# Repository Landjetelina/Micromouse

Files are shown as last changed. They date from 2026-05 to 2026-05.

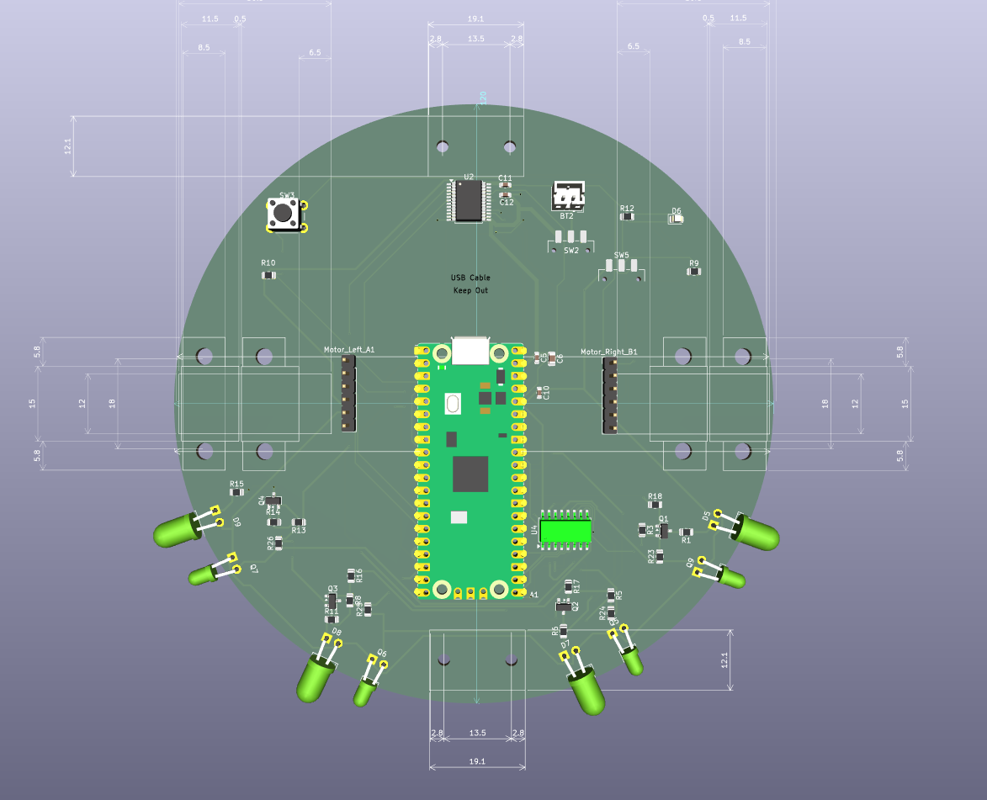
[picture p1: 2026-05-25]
hardware/pcb_3d.png

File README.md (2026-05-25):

# Šnajderovi šamani
- Magdalena Grbavac
- Patrik Landeka
- Antea Parat

## Natjecanje: 
31.5. u Algebri -> [Lokacija na karti](https://maps.app.goo.gl/GhEoACbUTYHz3x7r8)

## Requirements:
- Kicad = hardware dizajn
- VScode -> eksetenzija MicroPico
- micro USB podatkovni kabel (stari punjač od mobitela koji podržava prenošenje podataka, a ne samo punjenje)

### Tips:
- klonirajte ovaj repo u VScode pa odmah imate pristup kodovima
- za updejt datoteke:

  ```
  1. git add .
  2. git commit -m "poruka koja ide s promjenom"
  3. git push origin main *ako javlja grešku prvo napraviti pull
  4. git pull origin main * po potrebi, preporučam da to bude prvi korak ako niste zadnji radili na projektu
  ```

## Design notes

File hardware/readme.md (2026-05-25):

# Micromouse Hardware

Autonomous maze-solving robot based on Raspberry Pi Pico.

## Components

| Component | Description |
|---|---|
| Raspberry Pi Pico | Main microcontroller (RP2040) |
| TB6612FNG | Dual motor driver |
| TSAL6102 | IR LED emitter (940nm) x4 |
| TEFT4300 | IR phototransistor x4 |
| CD74HC4053 | Analog multiplexer (4:1) |
| N20 motors | DC motors with encoders x2

## Pin Assignment

| GPIO | Signal | Description 
|--- |---|---
| GPIO0 | IR_left | IR LED emitter - left 
| GPIO1 | IR_left-right | IR LED emitter - left-center 
| GPIO2 | IR_right-left | IR LED emitter - right-center 
| GPIO3 | IR_right | IR LED emitter - right 
| GPIO4 | Left_motor_1 | Motor driver AIN1 
| GPIO5 | Left_motor_2 | Motor driver AIN2
| GPIO6 | Right_motor_1 | Motor driver BIN1 
| GPIO7 | Right_motor_2 | Motor driver BIN2 
| GPIO8 | Speed_Left | PWM left motor 
| GPIO9 | Speed_Right | PWM right motor 
| GPIO10  | A1 | Encoder left A 
| GPIO11  | A2 | Encoder left B 
| GPIO12  | B1 | Encoder right A 
| GPIO13  | B2 | Encoder right B 
| GPIO16  | MUX_foto_0 | MUX select S0 
| GPIO17  | MUX_foto_1 | MUX select S1 
| GPIO18  | MUX_foto_2 | MUX select S2 
| GPIO26  | IRT_READ | ADC - phototransistor via MUX 

## Schematics

Designed in KiCad 10.0.0.
See `project1.kicad_sch` for full schematic.

## IR Sensor Circuit

Each IR pair consists of:
- **TSAL6102** emitter with 100Ω series resistor (3.3V)
- **TEFT4300** phototransistor with 10kΩ pull-up to 3.3V
- 4 phototransistors multiplexed through CD74HC4053 to single ADC pin

## Motor Driver

TB6612FNG driven at 3.3V logic, motor supply from LiPo battery via VSYS.
PWM frequency: 1kHz.

## Power

- LiPo single cell (3.7V) via JST PH connector
- VSYS powers motor driver
- 3.3V rail powers logic and sensors

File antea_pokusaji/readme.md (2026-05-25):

## Popravci, opažanja
- fotosenzori su bili obrnuti, Q5 je skroz zamjenjen => sad rade svi
- rad IR ledice moguć provjeriti s kamerom
- kvalitetnija brzina okretanja dobije se frekvencijomm 500 umjesto 1000 (manje modificiranja brzine)
- zamjenjeni su motor left i right na pcbu ("sjever" su ledice, znači desni je left, a lijevi je right --> napisano markerom)
- ne stisnuti kotače do kraja jer osovina izlazi kod konektora i ako ju tamo nešto češe, ide sporije
- bolje jedna umjesto 2 coaster balls (u suprotnom se jako jako jako slabo kreće), dovoljno je težak straga i ide sporo da to ne bi trebao biti problem + baterija premještena gore da ne smeta u vožnji 
- da bi se program pokrenuo treba biti nazvan "main.py"
- reset tipka ne radi ništa kada je uploadan program na robota, samo na sekundu ga zaustavi i normalno nastavlja dalje
- pri uključenju na laptop, pokreće se uploadani program jer pico vidi dovod napona s laptopa no onda ne rade baš fototranz (nez zaš, to je neki bug, jer "run this file on pico" i "upload this file" rade normalno i bez problemma)

### prebacivanje programa
1. desni klik na program i "upload file"
2. provjera pohrane se može preko ispod navedenih komandi
3. isključiti pico od laptopa, OFF pa ON i onda će sam krenuti

### terminal i provjera pohrane
``` 
import os
os.listdir()
os.remove()
```

### ideje za daljnju implementaciju 
- mapiranje "desnom rukom" bi moglo trajati iznimno dugo s obzirom da je brzina motora užasna
- zadržati frekveniciju motora na 500, eventualno malo sniziti da se smanji pogreška
- razmotriti potrebu PID regulatora

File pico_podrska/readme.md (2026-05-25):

RPI_PICO... = firmware za Pico 
- držati bootset (bijela tipka na Picu) dok se uštekava u komp
- kad se otvori skočni prozor file explorera za Pico, drag and drop .uf2 file na njega
- prozor će se zatvoriti i to će biti to, firmware je postavljen

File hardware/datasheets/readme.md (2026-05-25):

Datasheets komponenti koje su nam bitne
- Raspberry Pi Pico
- IR ledice
- fototranzistori
- N20 DC motori s enkoderima
- motor driver
- mux

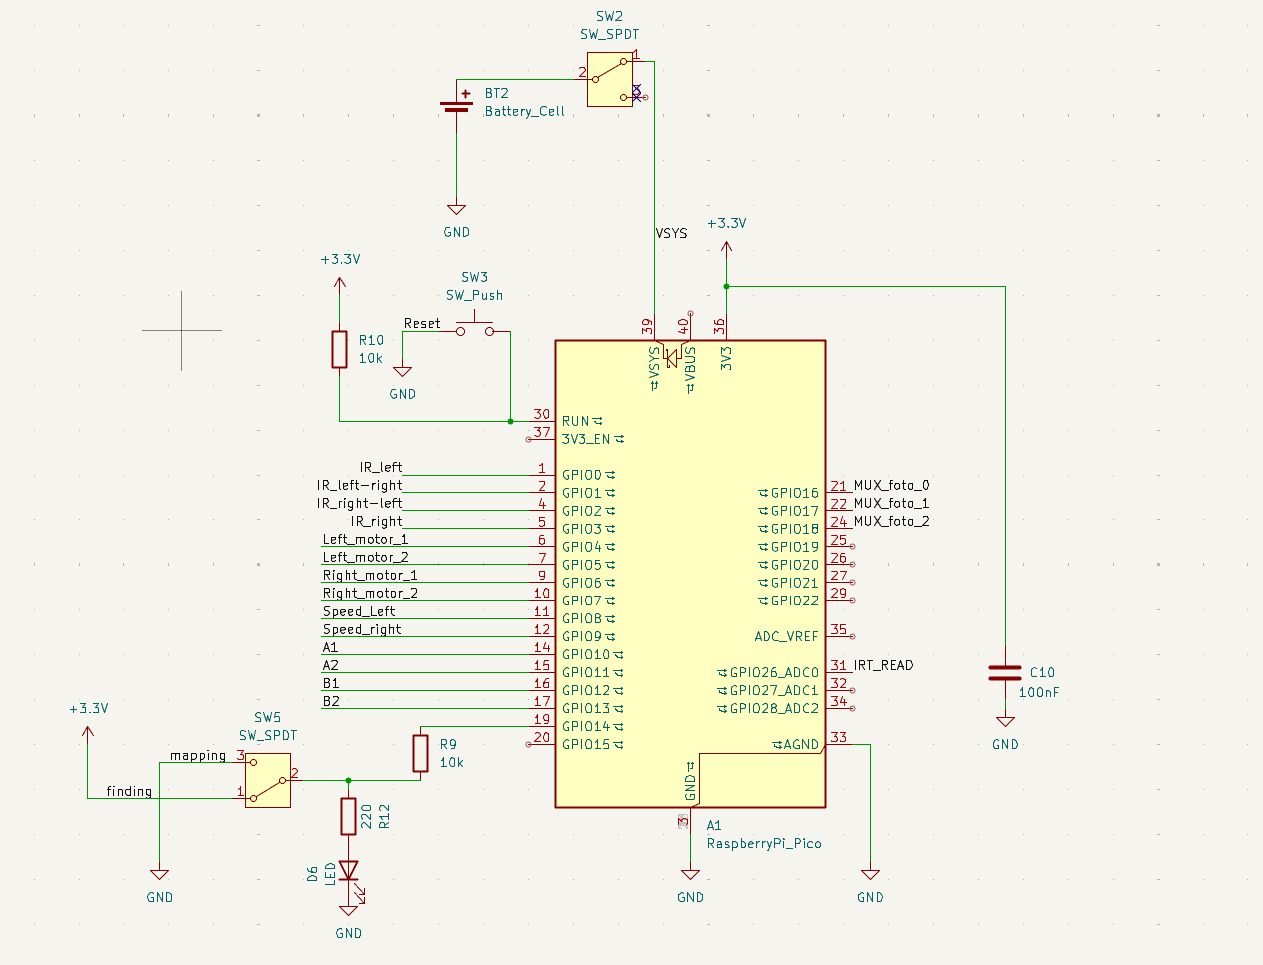
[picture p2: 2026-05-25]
hardware/pico.png

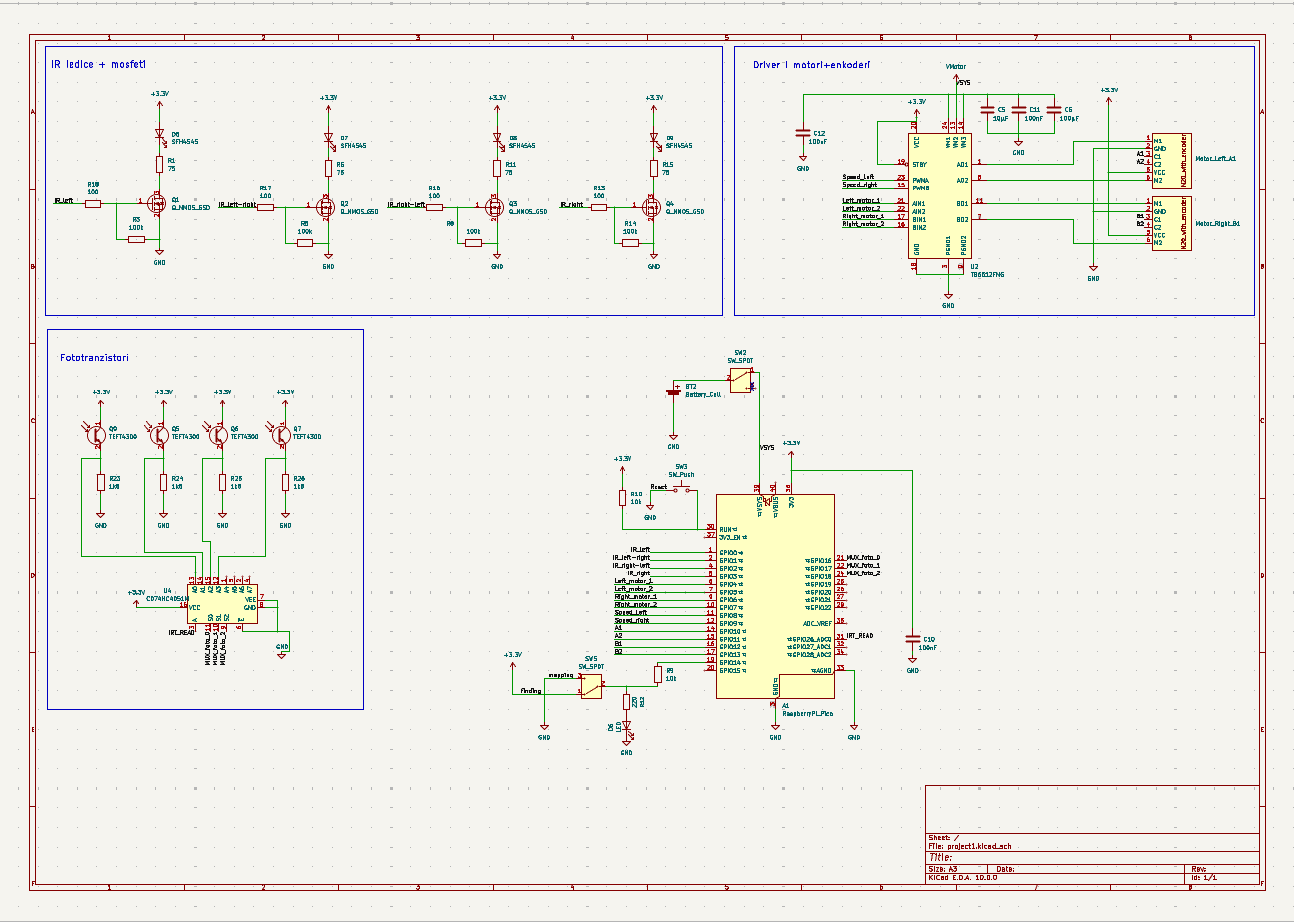
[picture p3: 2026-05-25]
hardware/shema.png

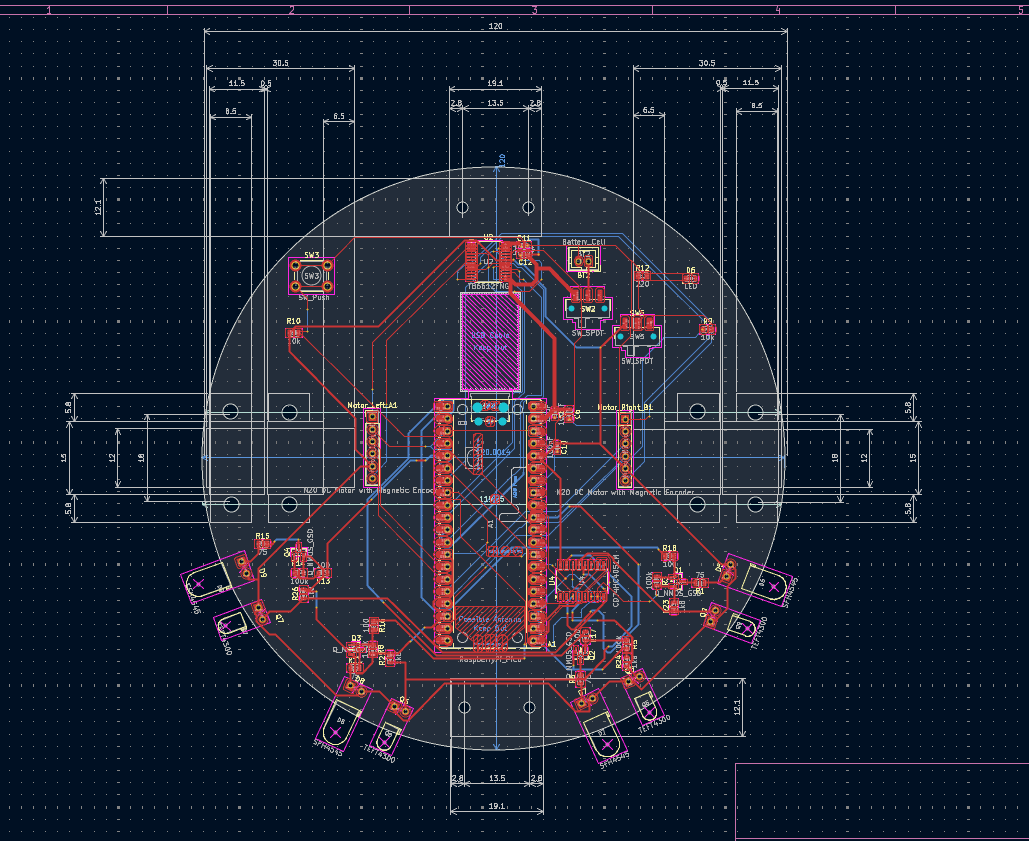
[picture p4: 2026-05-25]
hardware/pcb.png

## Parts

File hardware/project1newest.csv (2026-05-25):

Reference | Qty | Order Qty | Value | DNP | Exclude from BOM | Exclude from Board | Footprint | Datasheet | MPN | Manufacturer | Mouser | Polulu #item
A1 | 1 | 1 | RaspberryPi_Pico |  |  |  | Module:RaspberryPi_Pico_Common_Unspecified | https://datasheets.raspberrypi.com/pico/pico-datasheet.pdf | RP2040-PICO-HDR | Olimex Ltd. | 909-RP2040-PICO-HDR
BT2 | 1 | 1 | Battery_Cell |  |  |  | Connector_JST:JST_PH_B2B-PH-K_1x02_P2.00mm_Vertical |  | B2B-PH-K-S(LF)(SN) | JST Commercial | 306-B2BPHKSLFSNPP
C5 | 1 | 3 | 10ÂµF |  |  |  | Capacitor_SMD:C_0603_1608Metric |  | GRM188R60J106ME47D | Murata Electronics | 81-GRM188R60J106ME47
C6 | 1 | 3 | 100ÂµF |  |  |  | Capacitor_SMD:C_0805_2012Metric |  | GRM21BR60G107ME1L | Murata Electronics | 81-GRM21BR60G107ME1L
C10,C11,C12 | 3 | 6 | 100nF |  |  |  | Capacitor_SMD:C_0603_1608Metric |  | GRM188R72A104KA35D | Murata Electronics | 81-GRM188R72A104KA35
D1,D2,D3,D4 | 4 | 8 | TSAL6102 |  |  |  | LED_THT:LED_D5.0mm_Horizontal_O3.81mm_Z3.0mm |  | TSAL6102 | Vishay Semiconductors | 78-TSAL6102
D6 | 1 | 1 | LED |  |  |  | LED_SMD:LED_0805_2012Metric |  | 604-APT1608CGCK | Kingbright | 604-APT1608CGCK
Motor_Left_A1,Motor_Right_B1 | 2 | 2 | N20 DC Motor with Magnetic Encoder |  |  |  | Connector_PinHeader_2.54mm:PinHeader_1x06_P2.54mm_Vertical |  | 4639 | Adafruit | 485-4639
Q1,Q2,Q3,Q4 | 4 | 8 | Q_NMOS_GSD |  |  |  | Package_TO_SOT_SMD:SOT-23 |  | SI2302CDS-T1-GE3 | Vishay Semiconductors | 781-SI2302CDS-T1-GE3
Q5,Q6,Q7,Q9 | 4 | 8 | TEFT4300
R1,R6,R11,R15 | 4 | 8 | 68 |  |  |  | Resistor_SMD:R_0805_2012Metric |  | CRCW080568R0FKEA | Vishay | 71-CRCW080568R0FKEA
R3,R5,R8,R14 | 4 | 8 | 100k |  |  |  | Resistor_SMD:R_0805_2012Metric |  | CRCW0805100KFKEAC | Vishay | 71-CRCW0805100KFKEAC
R9,R10 | 2 | 6 | 10k |  |  |  | Resistor_SMD:R_0805_2012Metric |  | CRCW080510K0FKEAC | Vishay | 71-CRCW080510K0FKEAC
R12 | 1 | 3 | 220 |  |  |  | Resistor_SMD:R_0805_2012Metric |  | CRCW0805220RFKEAC | Vishay | 71-CRCW0805220RFKEAC
R13,R16,R17,R18 | 4 | 8 | 100 |  |  |  | Resistor_SMD:R_0805_2012Metric |  | CRCW0805100RFKEAC | Vishay | 71-CRCW0805100RFKEAC
R23,R24,R25,R26 | 4 | 8 | 1k8 |  |  |  | Resistor_SMD:R_0805_2012Metric |  | CRCW08051K80FKEAC | Vishay | 71-CRCW08051K80FKEAC
SW2,SW5 | 2 | 3 | SW_SPDT |  |  |  | Button_Switch_SMD:SW_SPDT_CK_JS102011SAQN |  | JS102011SAQN | C&K | 611-JS102011SAQN
SW3 | 1 | 2 | SW_Push |  |  |  | Button_Switch_THT:SW_PUSH_6mm |  | TL1105SPF160Q | E-Switch | 612-TL1105SP
U2 | 1 | 1 | TB6612FNG |  |  |  | Package_SO:SSOP-24_5.3x8.2mm_P0.65mm | https://toshiba.semicon-storage.com/us/product/linear/motordriver/detail.TB6612FNG.html | TB6612FNG,C,8,EL | Toshiba | 757-TB6612FNGC8EL
U4 | 1 | 1 | CD74HC4051M |  |  |  | Package_SO:SOIC-16_4.55x10.3mm_P1.27mm | http://www.ti.com/lit/ds/symlink/cd74hc4051.pdf | CD74HC4051M96 | Texas Instruments | 595-CD74HC4051M96
Brackets za motore par | 2 | 3 |  |  |  |  |  | https://www.pololu.com/product/989/specs#lightbox-picture0J771;main-pictures |  |  |  | 989
Kotaèi par (32x7mm) | 1 | 2 |  |  |  |  |  |  |  |  |  | 1088
kuglica (10mm = 0.375 in) | 2 | 4 |  |  |  |  |  | https://www.pololu.com/file/0J1636/pololu-ball-caster-with-0-375in-ball.pdf |  |  |  | 950

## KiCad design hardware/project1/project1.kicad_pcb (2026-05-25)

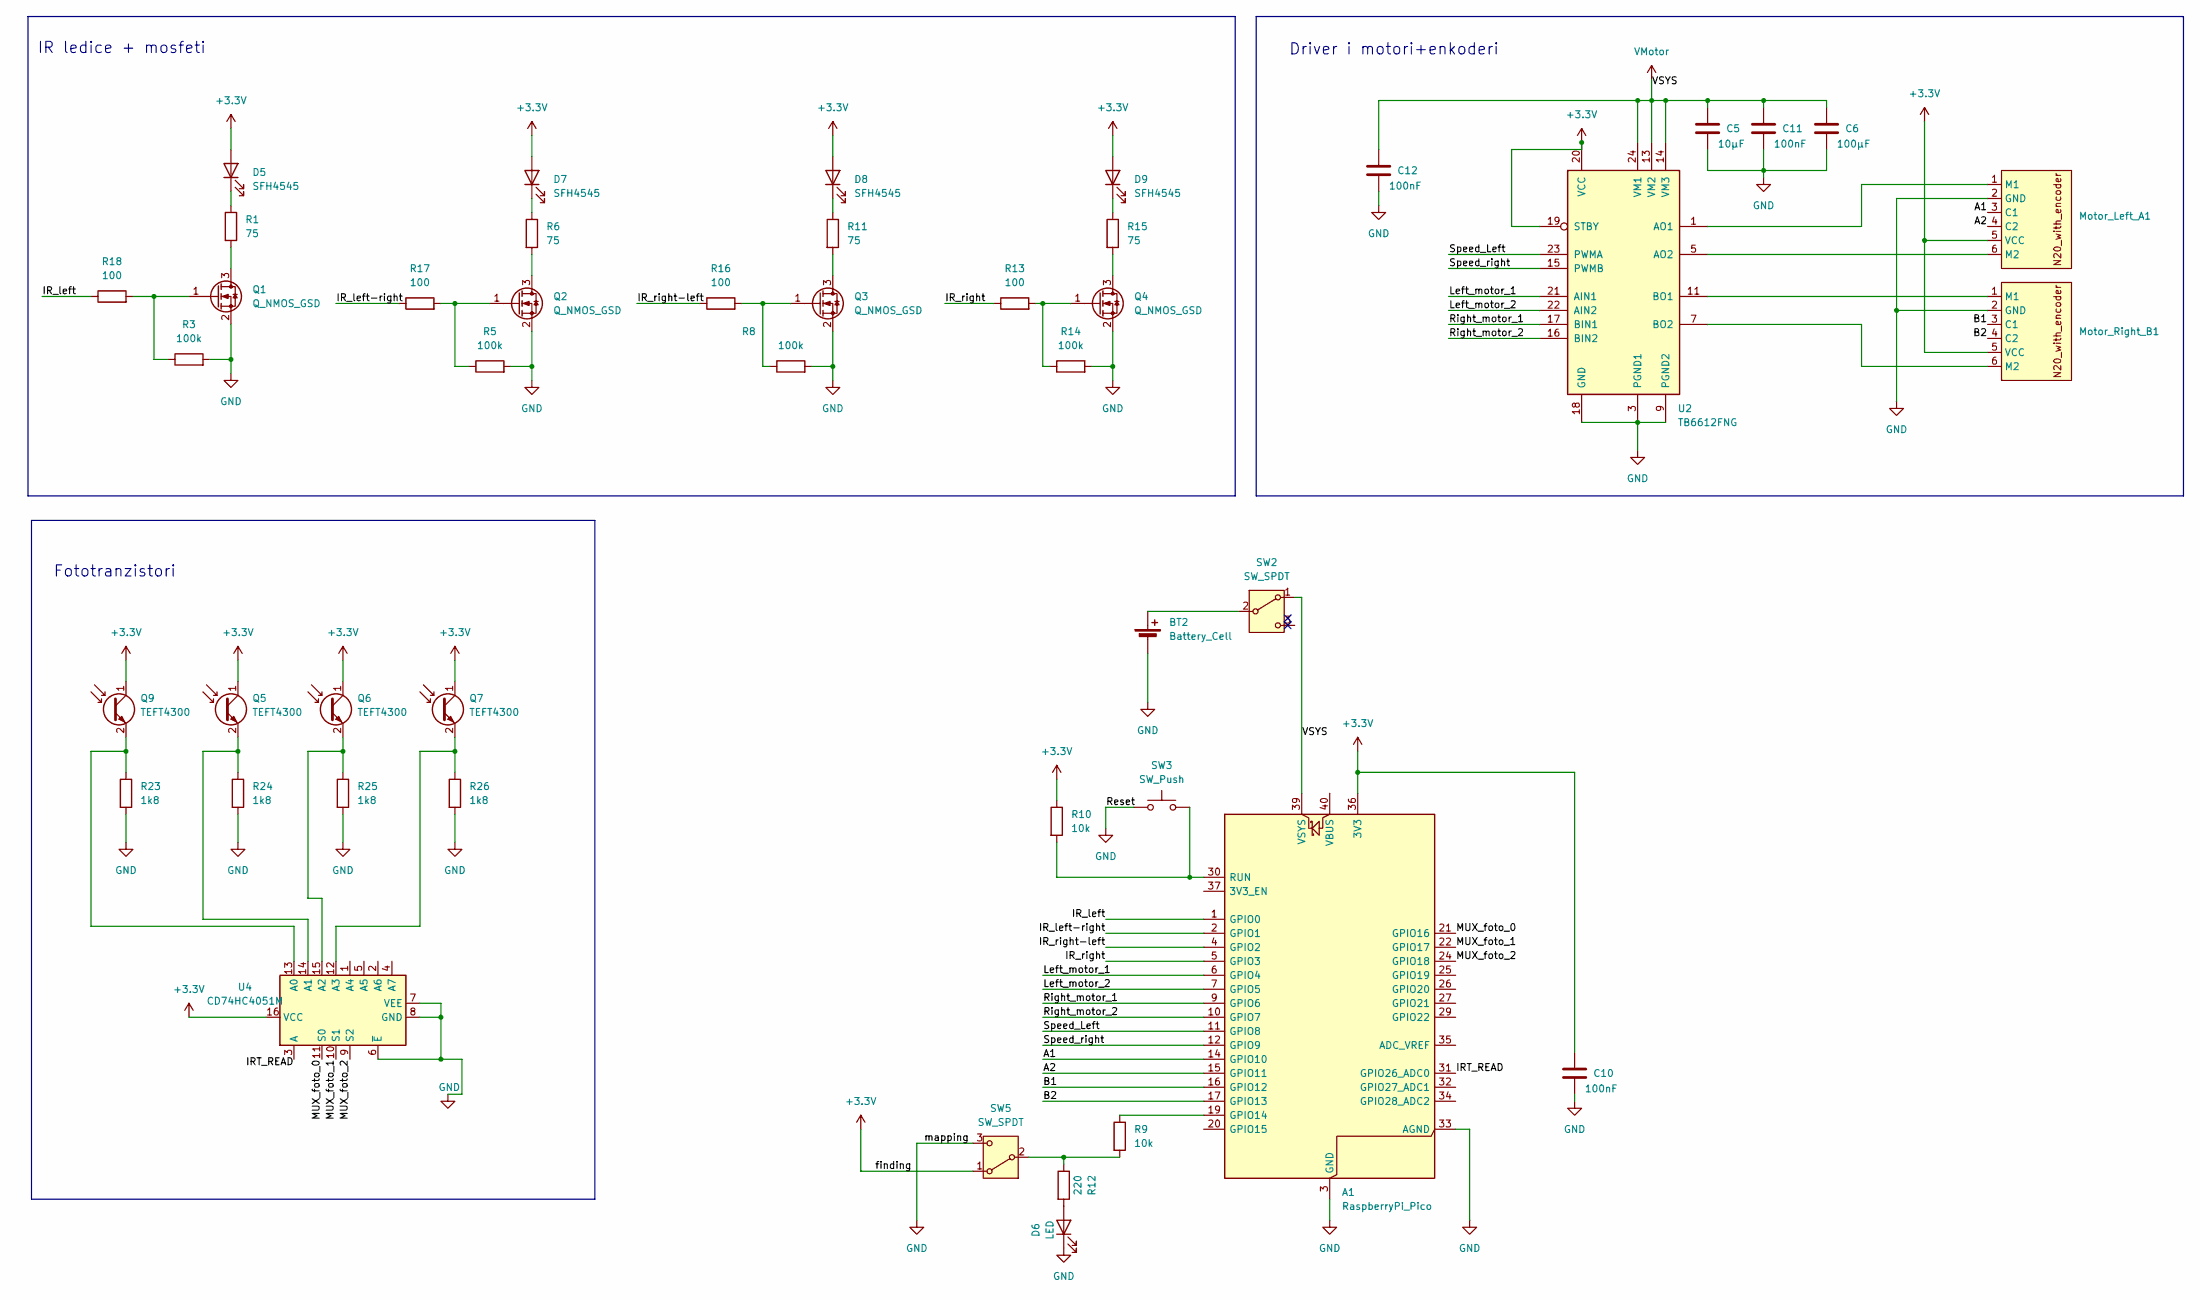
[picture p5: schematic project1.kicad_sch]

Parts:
A1: RaspberryPi_Pico; RaspberryPi_Pico_Common_Unspecified; MPN RP2040-PICO-HDR; Mouser 909-RP2040-PICO-HDR
BT2: Battery_Cell; JST_PH_B2B-PH-K_1x02_P2.00mm_Vertical; MPN B2B-PH-K-S(LF)(SN); Mouser 306-B2BPHKSLFSNPP
C5: 10µF; C_0603_1608Metric; MPN GRM188R60J106ME47D; Mouser 81-GRM188R60J106ME47
C6: 100µF; C_0805_2012Metric; MPN GRM21BR60G107ME1L; Mouser 81-GRM21BR60G107ME1L
C10, C11, C12: 100nF; C_0603_1608Metric; MPN GRM188R72A104KA35D; Mouser 81-GRM188R72A104KA35
D5, D7, D8, D9: SFH4545; LED_D5.0mm_Horizontal_O3.81mm_Z3.0mm; Manufacturer_Part_Number SFH 4545
D6: LED; LED_0805_2012Metric; MPN 604-APT1608CGCK; Mouser 604-APT1608CGCK
Motor_Left_A1: N20 DC Motor with Magnetic Encoder; PinHeader_1x06_P2.54mm_Vertical; MPN 4639; Mouser 485-4639
Motor_Right_B1: N20 DC Motor with Magnetic Encoder; PinHeader_1x06_P2.54mm_Vertical; MPN 4639; Mouser 485-4639
Q1, Q2, Q3, Q4: Q_NMOS_GSD; SOT-23; MPN SI2302CDS-T1-GE3; Mouser 781-SI2302CDS-T1-GE3
Q5, Q6, Q7, Q9: TEFT4300; LED_D3.0mm_Horizontal_O3.81mm_Z2.0mm; Manufacturer_Part_Number TEFT4300
R1, R6, R11, R15: 75; R_0805_2012Metric; MPN CRCW080568R0FKEA; Mouser 71-CRCW080568R0FKEA
R3, R5, R8, R14: 100k; R_0805_2012Metric; MPN CRCW0805100KFKEAC; Mouser 71-CRCW0805100KFKEAC
R9, R10: 10k; R_0805_2012Metric; MPN CRCW080510K0FKEAC; Mouser 71-CRCW080510K0FKEAC
R12: 220; R_0805_2012Metric; MPN CRCW0805220RFKEAC; Mouser 71-CRCW0805220RFKEAC
R13, R16, R17, R18: 100; R_0805_2012Metric; MPN CRCW0805100RFKEAC; Mouser 71-CRCW0805100RFKEAC
R23, R24, R25, R26: 1k8; R_0805_2012Metric; MPN CRCW08051K80FKEAC; Mouser 71-CRCW08051K80FKEAC
SW2, SW5: SW_SPDT; SW_SPDT_CK_JS102011SAQN; MPN JS102011SAQN; Mouser 611-JS102011SAQN
SW3: SW_Push; SW_PUSH_6mm; MPN TL1105SPF160Q; Mouser 612-TL1105SP
U2: TB6612FNG; SSOP-24_5.3x8.2mm_P0.65mm; MPN TB6612FNG,C,8,EL; Mouser 757-TB6612FNGC8EL
U4: CD74HC4051M; SOIC-16_4.55x10.3mm_P1.27mm; MPN CD74HC4051M96; Mouser 595-CD74HC4051M96

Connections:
+3.3V: A1.36 (3V3), C10.1, D5.2 (A), D7.2 (A), D8.2 (A), D9.2 (A), Motor_Left_A1.5 (VCC), Motor_Right_B1.5 (VCC), Q5.1 (C), Q6.1 (C), Q7.1 (C), Q9.1 (C), R10.1, SW5.1 (A), U2.19 (STBY), U2.20 (VCC), U4.16 (VCC)
/A1: A1.14 (GPIO10), Motor_Left_A1.3 (C1)
/A2: A1.15 (GPIO11), Motor_Left_A1.4 (C2)
/B1: A1.16 (GPIO12), Motor_Right_B1.3 (C1)
/B2: A1.17 (GPIO13), Motor_Right_B1.4 (C2)
/IRT_READ: A1.31 (GPIO26_ADC0), U4.3 (A)
/IR_left: A1.1 (GPIO0), R18.1
/IR_left-right: A1.2 (GPIO1), R17.1
/IR_right: A1.5 (GPIO3), R13.1
/IR_right-left: A1.4 (GPIO2), R16.1
/Left_motor_1: A1.6 (GPIO4), U2.21 (AIN1)
/Left_motor_2: A1.7 (GPIO5), U2.22 (AIN2)
/MUX_foto_0: A1.21 (GPIO16), U4.11 (S0)
/MUX_foto_1: A1.22 (GPIO17), U4.10 (S1)
/MUX_foto_2: A1.24 (GPIO18), U4.9 (S2)
/Right_motor_1: A1.9 (GPIO6), U2.17 (BIN1)
/Right_motor_2: A1.10 (GPIO7), U2.16 (BIN2)
/Speed_Left: A1.11 (GPIO8), U2.23 (PWMA)
/Speed_right: A1.12 (GPIO9), U2.15 (PWMB)
GND: A1.3 (GND), A1.8 (GND), A1.13 (GND), A1.18 (GND), A1.23 (GND), A1.28 (GND), A1.33 (AGND), A1.38 (GND), BT2.2 (-), C5.2, C6.2, C10.2, C11.2, C12.2, D6.1 (K), Motor_Left_A1.2 (GND), Motor_Right_B1.2 (GND), Q1.2 (S), Q2.2 (S), Q3.2 (S), Q4.2 (S), R3.2, R5.2, R8.2, R14.2, R23.2, R24.2, R25.2, R26.2, SW3.1, SW5.3 (C), U2.3 (PGND1), U2.4 (PGND1), U2.9 (PGND2), U2.10 (PGND2), U2.18 (GND), U4.6 (~E), U4.7 (VEE), U4.8 (GND)
unnamed: A1.19 (GPIO14), R9.1
unnamed: A1.30 (RUN), R10.2, SW3.2
unnamed: BT2.1 (+), SW2.2 (B)
unnamed: D5.1 (K), R1.1
unnamed: D6.2 (A), R12.2
unnamed: D7.1 (K), R6.1
unnamed: D8.1 (K), R11.1
unnamed: D9.1 (K), R15.1
unnamed: Motor_Left_A1.1 (M1), U2.1 (AO1), U2.2 (AO1)
unnamed: Motor_Left_A1.6 (M2), U2.5 (AO2), U2.6 (AO2)
unnamed: Motor_Right_B1.1 (M1), U2.11 (BO1), U2.12 (BO1)
unnamed: Motor_Right_B1.6 (M2), U2.7 (BO2), U2.8 (BO2)
unnamed: Q1.3 (D), R1.2
unnamed: Q1.1 (G), R3.1, R18.2
unnamed: Q2.3 (D), R6.2
unnamed: Q2.1 (G), R5.1, R17.2
unnamed: Q3.3 (D), R11.2
unnamed: Q3.1 (G), R8.1, R16.2
unnamed: Q4.3 (D), R15.2
unnamed: Q4.1 (G), R13.2, R14.1
unnamed: Q5.2 (E), R24.1, U4.14 (A1)
unnamed: Q6.2 (E), R25.1, U4.15 (A2)
unnamed: Q7.2 (E), R26.1, U4.12 (A3)
unnamed: Q9.2 (E), R23.1, U4.13 (A0)
unnamed: R9.2, R12.1, SW5.2 (B)
VMotor: A1.39 (VSYS), C5.1, C6.1, C11.1, C12.1, SW2.1 (A), U2.13 (VM2), U2.14 (VM3), U2.24 (VM1)

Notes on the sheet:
Driver i motori+enkoderi
IR ledice + mosfeti
Fototranzistori

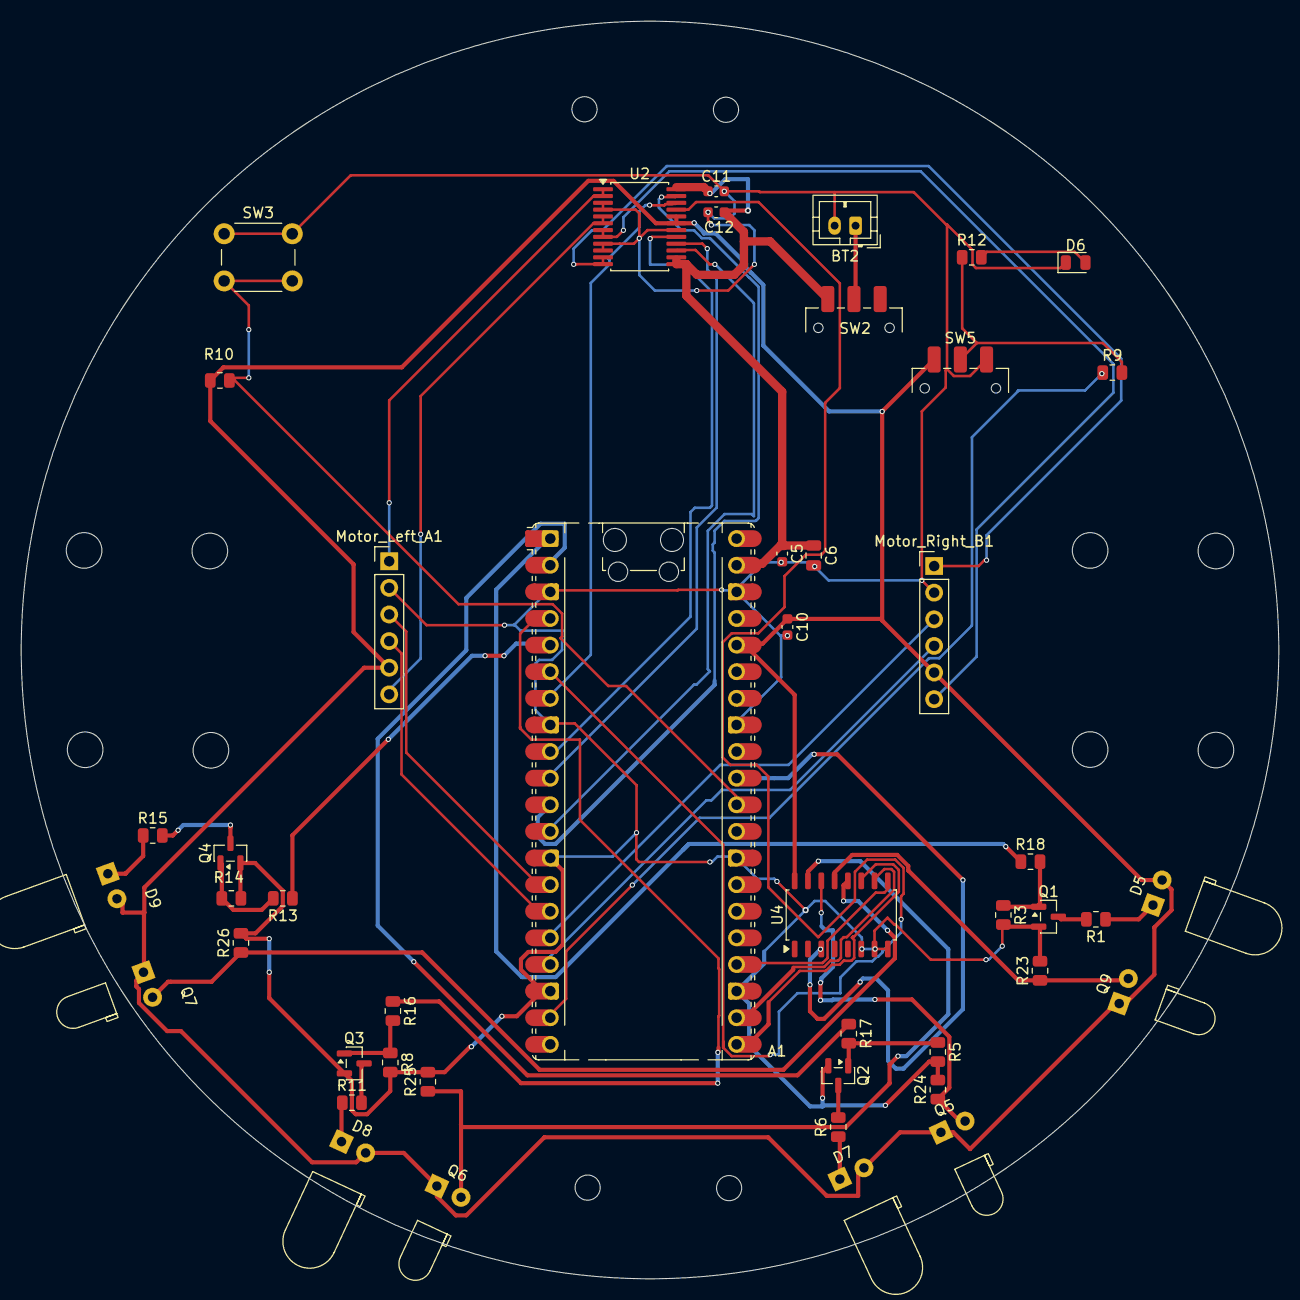
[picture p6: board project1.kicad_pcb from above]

Board: 2 copper layers, 120.0 x 120.0 mm, 46 parts (0 on the bottom side), 46 nets.

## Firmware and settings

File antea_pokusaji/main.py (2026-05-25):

from machine import Pin, PWM, ADC
import time

# IR LED kontrola (pali emitere)
ir_led = [
    Pin(0, Pin.OUT),  # IR_left
    Pin(1, Pin.OUT),  # IR_left-right
    Pin(2, Pin.OUT),  # IR_right-left
    Pin(3, Pin.OUT),  # IR_right
]

# MUX select (odabir kojeg fototranzistora čitaš)
mux_s = [
    Pin(16, Pin.OUT),  # MUX_foto_0
    Pin(17, Pin.OUT),  # MUX_foto_1
    Pin(18, Pin.OUT),  # MUX_foto_2
]

# ADC za čitanje MUX izlaza
adc = ADC(Pin(26))  # IRT_READ

#IMPORTANT - NA SHEMI I NA PCBU SU ZAMJENJENI MOTORI, LEFT TREBA BITI RIGH I OBRNUTA PA AKO NE VALJA DESNI MOTOR, TO JE ONDA LEFT (NAPISANO NA PLOČICI)
# Motor driver
left_motor_1  = Pin(4, Pin.OUT)
left_motor_2  = Pin(5, Pin.OUT)
right_motor_1 = Pin(6, Pin.OUT)
right_motor_2 = Pin(7, Pin.OUT)

speed_left  = PWM(Pin(8))
speed_right = PWM(Pin(9))
speed_left.freq(500)           # frekvencija PWM signala (1 kHz je dobar izbor za motore)
speed_right.freq(500)          # jer prevelika frekvencija može uzrokovati pregrijavanje motora, a premala može uzrokovati zujanje i neefikasno upravljanje brzinom

PRAG = 4000  # podesi eksperimentalno (0-65535) - vrijednost iznad koje se smatra da je prepreka detektirana

def mux_odaberi(kanal):
    # kanal 0-3 za 4 fototranzistora
    mux_s[0].value((kanal >> 0) & 1)
    mux_s[1].value((kanal >> 1) & 1)
    mux_s[2].value((kanal >> 2) & 1) 

def citaj_senzor(kanal):
    mux_odaberi(kanal)
    time.sleep_us(50)           # kratka pauza da se MUX stabilizira
    return adc.read_u16()       # to je fototranz na gpio26, koji je povezan na MUX izlaz

#100 000 ne postoji — duty_u16 je 16-bitni, maksimum je 65535. Sve iznad toga se "wraparound" ili baca grešku, ne daje više brzine
def motori_naprijed(brzina=45535):
    left_motor_1.value(1)  
    left_motor_2.value(0)
    right_motor_1.value(0)
    right_motor_2.value(1)
    speed_left.duty_u16(int(brzina * 1)) 
    speed_right.duty_u16(int(brzina * 1.015)) #Treba biti mrvu brži da bi išao ravno

def motori_stop():
    left_motor_1.value(0); left_motor_2.value(0)
    right_motor_1.value(0); right_motor_2.value(0)
    speed_left.duty_u16(0)
    speed_right.duty_u16(0)

# Upali sve IR LEDs
for led in ir_led:
    led.value(1)

while True:
    ocitanja = [citaj_senzor(k) for k in range(4)]
    prepreka = any(v > PRAG for v in ocitanja)

    print(f"Senzori: {ocitanja} | {'STOP' if prepreka else 'OK'}")

    if prepreka:
        motori_stop()
    else:
        motori_naprijed()

    time.sleep(0.05)        

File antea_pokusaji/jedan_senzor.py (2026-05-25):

from machine import Pin, ADC
import time

# Iz netliste: MUX select pinovi
mux_s = [
    Pin(16, Pin.OUT),  # MUX_foto_0 → GPIO16
    Pin(17, Pin.OUT),  # MUX_foto_1 → GPIO17
    Pin(18, Pin.OUT),  # MUX_foto_2 → GPIO18
]

# IR LED za kanal koji testiraš
# kanal 0 → IR_left (GPIO0), kanal 1 → IR_left-right (GPIO1), itd.
IR_LEDS = [
    Pin(0, Pin.OUT),   # IR_left
    Pin(1, Pin.OUT),   # IR_left-right
    Pin(2, Pin.OUT),   # IR_right-left
    Pin(3, Pin.OUT),   # IR_right
]

# ADC: IRT_READ → GPIO26
adc = ADC(Pin(26))

# SAMO TU MIJENJAJ OVE VARIJABLE
KANAL = 3   # 0–3, mijenjaj za testiranje
# 0 = IR_left (Q9) radi
# 1 = IR_left-right (Q5) radi
# 2 = IR_right-left (Q6) radi
# 3 = IR_right (Q7) radi
PRAG = 4000

def mux_odaberi(kanal):
    mux_s[0].value((kanal >> 0) & 1)
    mux_s[1].value((kanal >> 1) & 1)
    mux_s[2].value((kanal >> 2) & 1)


# optimalno je držati prag 3000-4000
# Upali samo IR LED za odabrani kanal
IR_LEDS[KANAL].value(1)
mux_odaberi(KANAL)

while True:
    time.sleep_us(50)
    vrijednost = adc.read_u16()
    prepreka = vrijednost > PRAG
    print(f"Kanal {KANAL}: {vrijednost} | {'PREPREKA' if prepreka else 'OK'}")
    time.sleep(0.1)

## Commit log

2026-05-22 Add hardware documentation for Micromouse project
    Added detailed documentation for the Micromouse hardware, including components, pin assignments, schematics, IR sensor circuit, motor driver, and power supply information.
2026-05-22 verzija3_popravljeno_predano
    moram probati još zipani kicad projekt
    [project1newest.csv]
2026-05-22 valjda je okej pushano
    skinite kao zip
    [project1.kicad_sch, project1newest.csv]
2026-05-22 Add firmware installation instructions for RPI Pico
    Added instructions for flashing firmware to RPI Pico.
2026-05-24 Update project1newest.csv with new component details
    [project1newest.csv]
2026-05-25 popravljeni senzori, probni program je main
    da bi pico samostalno pokrenuo program, navodno treba nazvati main
